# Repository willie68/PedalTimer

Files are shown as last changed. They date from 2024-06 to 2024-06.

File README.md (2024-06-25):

# PedalTimer

A small clock for your guitar pedal board, that counts up or down to measure the duration of songs or to time your performance when you are limited on time.

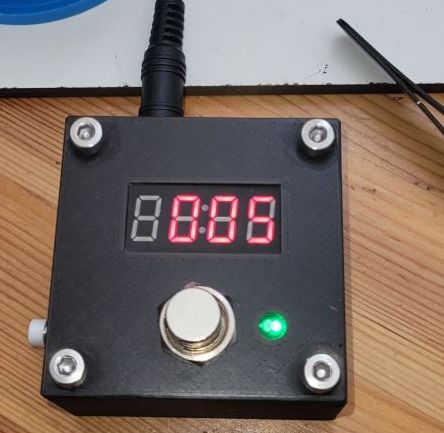
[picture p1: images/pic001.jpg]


The github project site: https://github.com/willie68/PedalTimer

For schematic see wokwi project: https://wokwi.com/projects/400030668740998145

For the case see https://www.tinkercad.com/things/1SspvxZFjsm-pedal-timer

# Description

## Introduction 

Pedal Timer is a small clock for your guitar pedal board. It can count up to measure the duration of songs or down to time your performance when you are limited on time. It can be easily configured even with your foot. 

It has a nice Display, showing time and a small multi color LED for showing the state of the Timer.

## Startup

First the unit show up the firmware of your device. (here it's the 0.06 Version)



After 2 Seconds the unit shows the actual mode



t: St means Stopwatch mode, which is the mode for measure times.

If configured in Count down mode, this will show up:



After another 2 seconds, the unit will switch to operating mode.



## Stopwatch mode

Now you are ready to measure times. A short press on the foot switch will start and stop the timer. You can start and stop as often as you like, the unit will always start from the former time. A long press will reset the timer. The time shown in `minutes:seconds`. This will work 'til 99:59, than an overun will happen (timer start again with 00:00) When running the LED will lit up green and the colon in the middle are blinking.

## Countdown Mode

The display always shows the remaining time in countdown mode.



Start/Stop/Reset works the same as in ST mode. When running the LED will lit up green and the colon in the middle are blinking. If the remaining time > 90 min, the display is showing the `hours:minutes`. If you under run the time, this is indicated by an minus in front of the time. 



## Configuration Mode

To start the configuration mode simply press and hold the button on start until you see the menu entry (after showing firmware and mode) , or do a double click, if St or cd is stopped:



for all steps in the configuration: single click means: next value, long press means: next Entry. The unit will always show the last configured value. if you can configure the value the LED will lit up blue. After the long press, the LED will be off and the configured value will be shown for 1 second. Than the display will show the next configuration value. On double click in every configuration you will exit the configuration without saving the actual config value.

### Brightness



First configuration is the display brightness. The value can range from 1..7. You will see the result only in normal operation modes. In configuration the brightness is always set to max. (So you can always see the display for configuration) 

### Operation Mode

  

There are 2 modes of operation: Stopwatch, shown by St and Count down shown by cd.

### Countdown time



Next you can configure the Countdown time in minutes. It ranges from 5 to 240 minutes  in 5 minutes steps. And it rolls over, so after 240 min -> 5 min. Long press stores the value.

### Warning time (Alarm)



You can setup a warning time from 0..15 min. 0 disables the warning. 

- **St mode**: the LED will lit up in RED (instead of green) if the elapsed time is longer than the warning time.

- **cd mode**: the LED will lit up in RED (instead of green) if the remaining time is shorter than the warning time.

# Building our own version

## BOM

What you need:

- arduino nano or compatible
- footswitch spst (single pole single throw) german: einen Fußtaster.
- 4x Digit TM1637 Display with  double point
- a 5mm RGB WS2812b short head LED
- a small SPST switch for manual input by hand
- 3d printed case
- 4 melting nuts M4 and 4 M4x9mm screws
- chicken feed (which means: cables, solder and stuff like that)

for 9V power

- lumberg DC socket
- 9V/5V converter

## Building up

Before you can start, if you have a nano, the display or any other component with pin heads, remove (desolder) them. In the case there is not enough room for that. Than build all up with short cables. Beware of the DC Socket. You have to solder it, after installing the socket. Because this is the only hardware part going from outside to inside. All others can be soldered before. Glue all the other parts into the case with  hot glue. For the RGB LED you can use super glue.  

Than you are ready to program the nano. The project is build with VS Code and Platform.IO. Simply load the project into VS Code and than you can program the nano. Maybe you have to switch the version for your nano. I have build this up with `nanoatmega328new`  but some other nanos where sold with an older boot loader so you have to use `nanoatmega328`. You can switch this in the platformio.ini file.

### building images

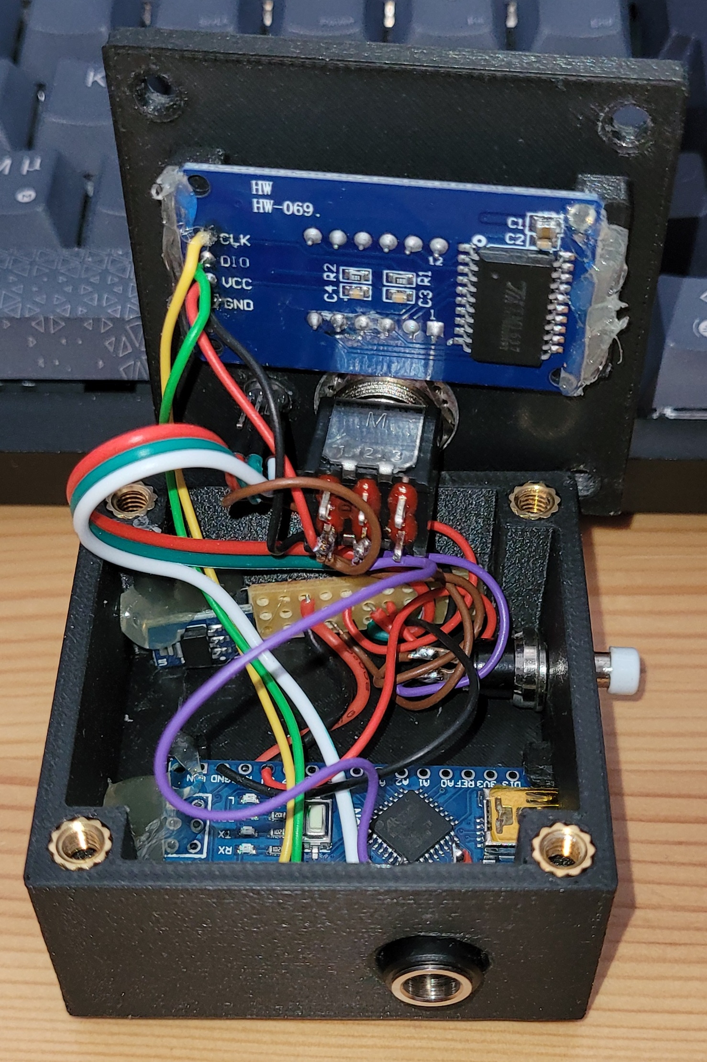
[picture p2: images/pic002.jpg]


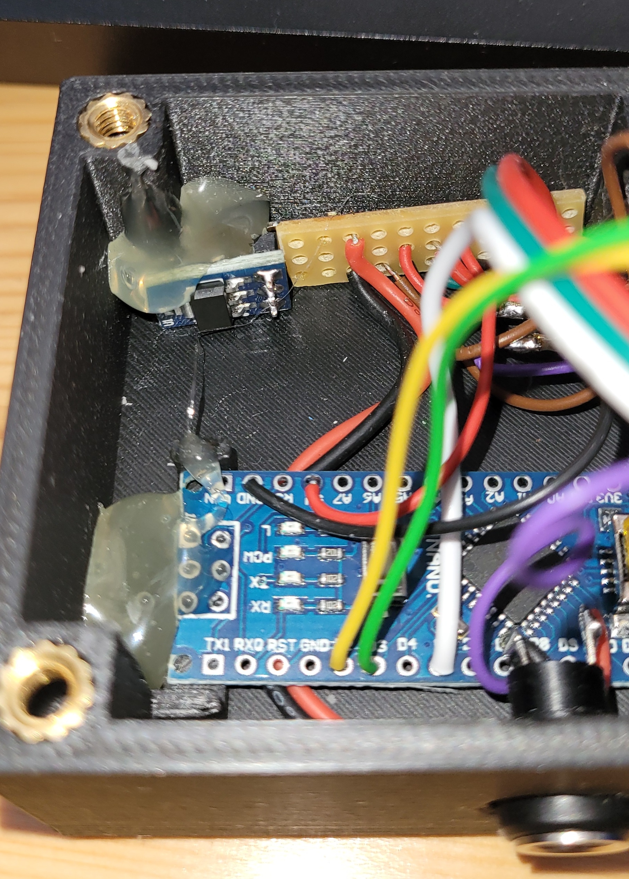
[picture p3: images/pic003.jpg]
Detail view of the power supply

## Schematics

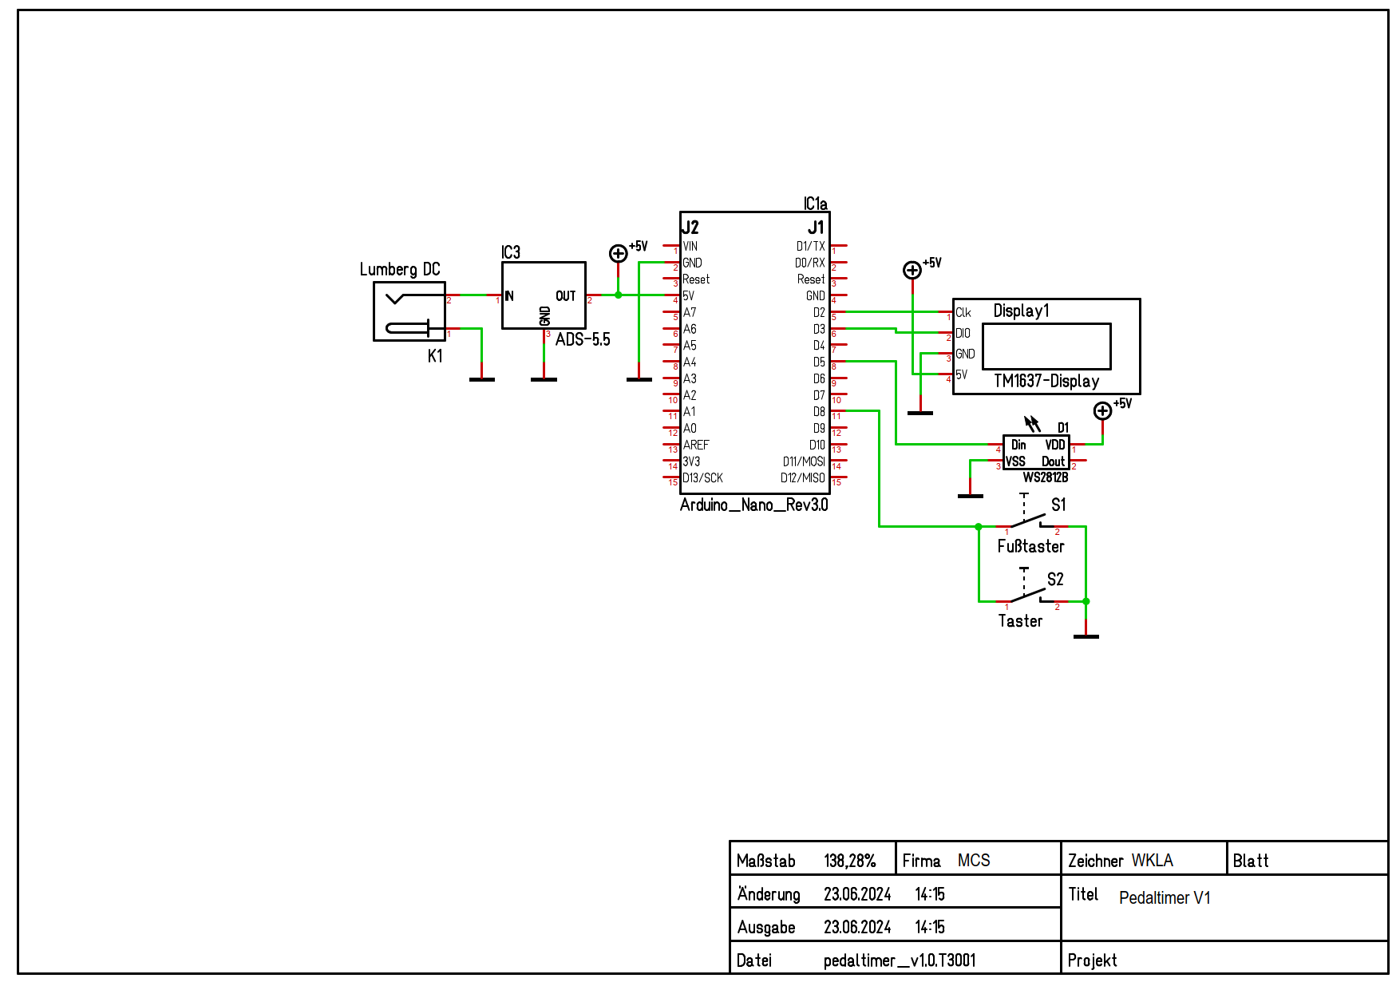
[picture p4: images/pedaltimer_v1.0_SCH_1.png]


<u>2024 WK-Music</u>

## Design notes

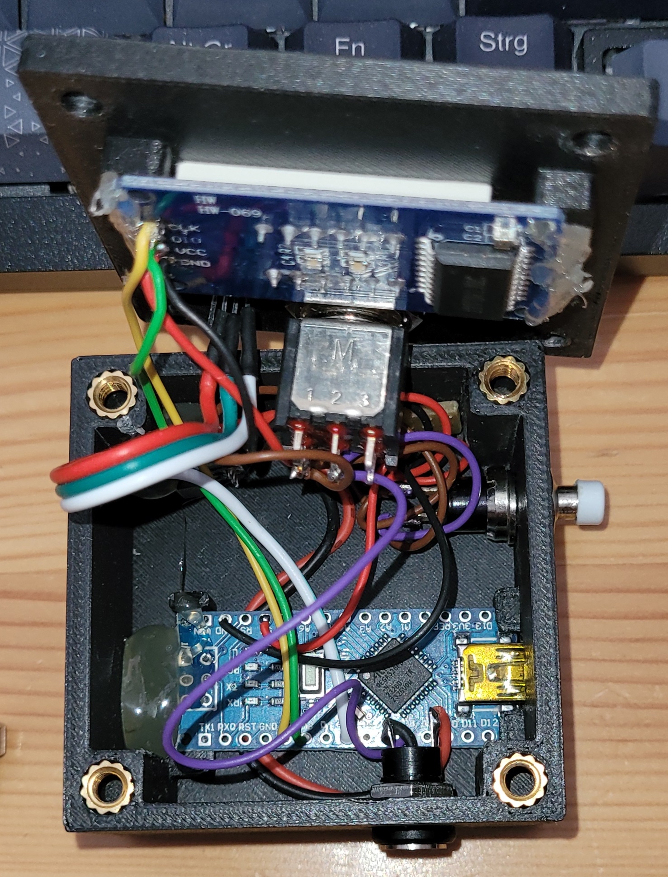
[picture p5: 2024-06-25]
images/pic004.jpg

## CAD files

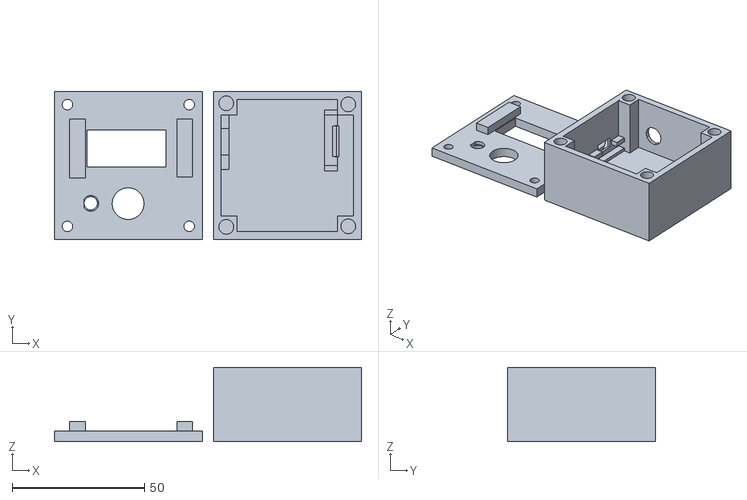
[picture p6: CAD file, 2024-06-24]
hardware/Pedal timer.stl
116.0 x 56.0 x 28.0

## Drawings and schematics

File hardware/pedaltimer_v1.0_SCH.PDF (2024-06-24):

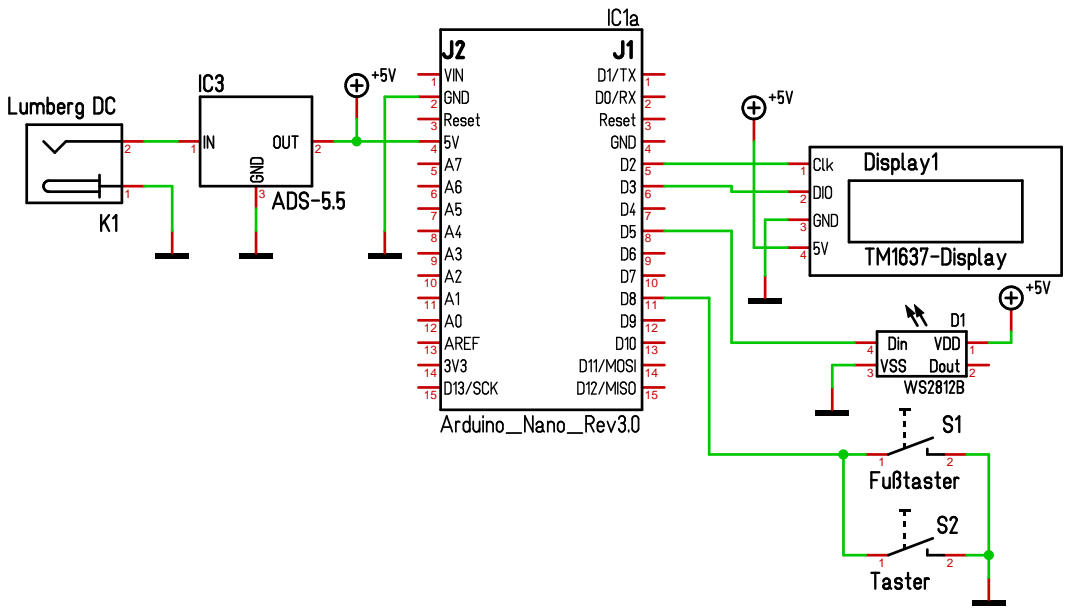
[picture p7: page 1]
Pedaltimer V1; MCS; WKLA ⁴³

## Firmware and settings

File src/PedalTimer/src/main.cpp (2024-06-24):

// this little Project is for my bandmates
// i have to measure the length of our songs,
// so i simply design this. A nano, a footbutton and a TM1637 display is all i need.
// short tap starts/stop/restart the timer
// long tap reset the timer, northing more
#include <arduino.h>
#include <TM1637Display.h>
#include "avdweb_Switch.h"
#include <eeprom.h>
#include <Adafruit_NeoPixel.h>

// #define debug
// #define serial

// Version
#define VS_MAJ 0
#define VS_MIN 8
// constants
#define ON 1
#define OFF 0
// Display
#define CLK 2
#define DIO 3
// Footswitch
#define FS 8
// RGB LED
#define LED_PIN 5

const uint8_t TTD[] = {SEG_F | SEG_G | SEG_E | SEG_D};
const uint8_t STD[] = {SEG_A | SEG_F | SEG_G | SEG_C | SEG_D, SEG_F | SEG_G | SEG_E | SEG_D};
const uint8_t CDD[] = {SEG_G | SEG_E | SEG_D, SEG_B | SEG_G | SEG_E | SEG_D | SEG_C};
const uint8_t CPD[] = {SEG_G | SEG_E | SEG_D};
const uint8_t MND[] = {SEG_G};
const uint8_t MED[] = {
    SEG_A | SEG_F | SEG_E | SEG_B | SEG_C,
    SEG_A | SEG_F | SEG_G | SEG_E | SEG_D,
    SEG_G | SEG_E | SEG_C,
    SEG_C | SEG_E | SEG_D,
};

// show the given time
void showTime(int act);
// lit the LED
void led(bool on);
// toggle the LED output
void toggled();
// checking if the LED is on
bool isLED();
// read the timer mode
void readCdm();
// do the timer setup
void doSetup();
// showing the given count down mode
void showCdm(bool mode);
// showing the count down time for setup
void setupCdmTimeShow(int time);
// showing the count down time
void showCdmTime(int time);
// write out the config via serial
void outputConfig();

Adafruit_NeoPixel pixel(1, LED_PIN, NEO_RGB + NEO_KHZ800);
TM1637Display display = TM1637Display(CLK, DIO);
Switch fs = Switch(FS);

const uint32_t RED = pixel.Color(0xff, 0, 0);
const uint32_t BLUE = pixel.Color(0, 0, 0xff);
const uint32_t GREEN = pixel.Color(0, 0xff, 0);

long start = 0L;
bool started = false;
bool ledOn = false;
// count down mode, if true the timer operate in count down mode.
// Taking the actual time from the eeprom and on first click starts the count down.
// Default mode is taken from the eeprom, too
bool cdm = true;
byte cdmtime = 45;
byte bright = 4;
// time to start the warning, blinking LED,
// in CD mode: time in minutes, when cd time is lower than this, the alarm starts
// in ST mode: time in minutes, when time is greater than this, the alarm starts
byte warningtime = 4;
bool alarm = false;
unsigned long alarmblk = 0;

// actual color of led
uint32_t color = GREEN;
bool endsetup = false;

void setupPixel()
{
  pixel.begin(); // INITIALIZE NeoPixel strip object (REQUIRED)
  pixel.setBrightness(7 * 8);
  pixel.show();

  color = BLUE;
}

void showVersion()
{
  display.clear();
  display.setBrightness(7);
  display.showNumberDec(VS_MAJ, false, 1, 1);
  display.showNumberDec(VS_MIN, true, 2, 2);
  display.showNumberHexEx(0xF, 0xF, false, 1, 0);

  led(ON);
  for (byte i = 0; i < 200; i++)
  {
    fs.poll();
    delay(10);
  }
}

void afterSetup()
{
#ifdef serial
  color = GREEN;
#endif

  outputConfig();
  display.clear();
  display.setBrightness(bright);
  pixel.setBrightness(bright * 8);
  cdm ? showCdmTime(0) : showTime(0);
  led(OFF);
}

void setup()
{
#ifdef serial
  Serial.begin(115200);
#endif

  setupPixel();

  showVersion();

  readCdm();
  display.clear();
  display.setSegments(TTD, 1, 0);
  showCdm(cdm);
  for (byte i = 0; i < 200; i++)
  {
    fs.poll();
    delay(10);
  }
  if (fs.on())
  {
    doSetup();
  }

  afterSetup();
}

long actualSec, oldSec = 0;
bool colon = false;

void loop()
{
  fs.poll();
  if (fs.doubleClick())
  {
    if (!started)
    {
      doSetup();
      afterSetup();
      actualSec = 0;
      start = 0L;
    }
  }
  if (fs.longPress())
  {
    started = false;
    actualSec = 0;
    colon = false;
    display.setColon(colon);
    led(OFF);
  }
  if (fs.singleClick())
  {
    if (!started)
    {
      started = true;
      start = millis() - (actualSec * 1000L);
      oldSec = -1;
    }
    else
    {
      started = false;
    }
    led(started);
    colon = started;
    display.setColon(colon);
  }
  if (started)
  {
    actualSec = (millis() - start) / 1000L;
    if (warningtime > 0)
    {
      if (cdm)
      {
        alarm = (int(cdmtime) * 60) - int(actualSec) < (int(warningtime) * 60);
      }
      else
      {
        alarm = actualSec > (warningtime * 60L);
      }
    }
    if (alarm)
    {
      color = RED;
      if (alarmblk < millis())
      {
        alarmblk = millis() + 500;
        toggled();
        display.setBrightness(7);
      }
    }
    else
    {
      color = GREEN;
    }
    led(started);
  }
  if (actualSec != oldSec)
  {
    display.setColon(colon);
    if (cdm)
    {
      showCdmTime(actualSec);
    }
    else
    {
      showTime(actualSec);
    }
    colon = !colon;
    oldSec = actualSec;
  }
}

void showTime(int act)
{
  bool neg = act < 0;
  int t = abs(act);
  byte sec = t % 60;
  byte min = (t - sec) / 60;
  if (neg)
  {
    display.setSegments(MND, 1, 0);
    display.showNumberDec(min, false, 1, 1);
  }
  else
  {
    display.showNumberDec(min, false, 2, 0);
  }
  display.showNumberDec(sec, true, 2, 2);
}

void showCdmTime(int ct)
{
  int time = (cdmtime * 60) - int(ct);
#ifdef serial
  Serial.println(time);
#endif
  if ((time <= 90 * 60) && (time > -9 * 60))
  {
    showTime(long(time));
  }
  else
  {
    int value = time / 60;
    // display.clear();
    display.showNumberDec(value, false, 4, 0);
  }
}

void led(bool on)
{
  if (!on)
  {
    pixel.clear();
    pixel.show();
  }
  else
  {
    pixel.setPixelColor(0, color);
    pixel.show();
  }
  ledOn = on;
}

void toggled()
{
  led(!isLED());
}

bool isLED()
{
  return ledOn;
}

void readCdm()
{
#ifdef debug
  cdm = true;
#else
  byte value = EEPROM.read(0x00);
  cdm = (value > 0) && (value < 0xFF);
  value = EEPROM.read(0x01);
  if (value <= 240)
  {
    cdmtime = value;
  }
  bright = EEPROM.read(0x02);
  if (bright == 0xff)
  {
    bright = 4;
  }
  bright = bright % 7;
  warningtime = EEPROM.read(0x03);
  if (warningtime == 0xff)
  {
    warningtime = 9;
  }
  warningtime = warningtime % 16;
#endif
}

void setupMode()
{
  led(ON);
  display.clear();
  display.setColon(ON);
  display.setSegments(TTD, 1, 0);
  showCdm(cdm);
  bool end = false;
  bool value = cdm;
  do
  {
    fs.poll();
    if (fs.doubleClick())
    {
      endsetup = true;
      return;
    }
    if (fs.longPress())
    {
      cdm = value;
      EEPROM.write(0x00, cdm ? 1 : 0);
      end = true;
    }
    else if (fs.singleClick())
    {
      value = !value;
      showCdm(value);
    }
  } while (!end);
  led(OFF);
  display.setColon(OFF);
  display.clear();
  display.setSegments(TTD, 1, 0);
  showCdm(cdm);
  delay(1000);
}

void setupCdmTimeShow(int time)
{
  display.setSegments(CPD, 1, 0);
  display.showNumberDec(time, true, 3, 1);
}

void setupCDTime()
{
  led(ON);
  display.setColon(OFF);
  display.clear();
  setupCdmTimeShow(cdmtime);
  bool end = false;
  byte value = cdmtime;
  do
  {
    if ((value > 240) || (value < 5))
    {
      value = 5;
      setupCdmTimeShow(value);
    }
    fs.poll();
    if (fs.doubleClick())
    {
      endsetup = true;
      return;
    }
    if (fs.longPress())
    {
      EEPROM.write(0x01, value);
      cdmtime = value;
      end = true;
    }
    else if (fs.singleClick())
    {
      value += 5;
      setupCdmTimeShow(value);
    }
  } while (!end);
  led(OFF);
  display.clear();
  setupCdmTimeShow(cdmtime);
  delay(1000);
}

void setupBrigthnessShow(byte value)
{
  display.showNumberHexEx(0xb, 0, false, 1, 0);
  display.showNumberDec(value, false, 1, 3);
}

void setupBrightness()
{
  led(ON);
  display.setColon(ON);
  display.clear();
  setupBrigthnessShow(bright);
  bool end = false;
  byte value = bright;
  do
  {
    if (value > 7)
    {
      value = 0;
      setupBrigthnessShow(value);
    }
    fs.poll();
    if (fs.doubleClick())
    {
      endsetup = true;
      return;
    }
    if (fs.longPress())
    {
      bright = value;
      EEPROM.write(0x02, value);
      end = true;
    }
    else if (fs.singleClick())
    {
      value++;
      setupBrigthnessShow(value);
    }
  } while (!end);
  led(OFF);
  display.setColon(OFF);
  display.clear();
  setupBrigthnessShow(bright);
  delay(1000);
}

void setupWarningTimeShow(byte value)
{
  display.showNumberHexEx(0xa, 0, false, 1, 0);
  display.showNumberDec(value, true, 2, 2);
}

void setupWarningTime()
{
  led(ON);
  display.setColon(ON);
  display.clear();
  setupWarningTimeShow(warningtime);
  bool end = false;
  byte value = warningtime;
  do
  {
    if (value > 15)
    {
      value = 0;
      setupWarningTimeShow(value);
    }
    fs.poll();
    if (fs.doubleClick())
    {
      endsetup = true;
      return;
    }
    if (fs.longPress())
    {
      warningtime = value;
      EEPROM.write(0x03, value);
      end = true;
    }
    else if (fs.singleClick())
    {
      value++;
      setupWarningTimeShow(value);
    }
  } while (!end);
  led(OFF);
  display.setColon(OFF);
  display.clear();
  setupWarningTimeShow(warningtime);
  delay(1000);
}

void doSetup()
{
  color = BLUE;
  endsetup = false;

  // show menu text
  display.clear();
  display.setColon(false);
  display.setSegments(MED, 4, 0);
  delay(2000);
  fs.poll();
  // setup display brightness
  setupBrightness();
  if (endsetup)
    return;
  // Set counter mode
  setupMode();
  if (endsetup)
    return;
  // now if cdm is selected, let's adjust the count down time
  setupCDTime();
  if (endsetup)
    return;
  // setup the warning time
  setupWarningTime();
  if (endsetup)
    return;
}

void showCdm(bool mode)
{
  if (mode)
  {
    display.setSegments(CDD, 2, 2);
  }
  else
  {
    display.setSegments(STD, 2, 2);
  }
}

void outputConfig()
{
  Serial.print("Bright: ");
  Serial.println(bright);
  Serial.print("Mode: ");
  Serial.println(cdm ? "countdown" : "stoptime");
  Serial.print("Warning time: ");
  Serial.println(warningtime);
  Serial.print("Countdown time: ");
  Serial.println(cdmtime);
}

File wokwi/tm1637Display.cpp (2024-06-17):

//  Author: avishorp@gmail.com
//
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
extern "C" {
  #include <stdlib.h>
  #include <string.h>
  #include <inttypes.h>
}

#include "tm1637Display.h"
#include <Arduino.h>

#define TM1637_I2C_COMM1    0x40
#define TM1637_I2C_COMM2    0xC0
#define TM1637_I2C_COMM3    0x80

//
//      A
//     ---
//  F |   | B
//     -G-
//  E |   | C
//     ---
//      D
const uint8_t digitToSegment[] = {
 // XGFEDCBA
  0b00111111,    // 0
  0b00000110,    // 1
  0b01011011,    // 2
  0b01001111,    // 3
  0b01100110,    // 4
  0b01101101,    // 5
  0b01111101,    // 6
  0b00000111,    // 7
  0b01111111,    // 8
  0b01101111,    // 9
  0b01110111,    // A
  0b01111100,    // b
  0b00111001,    // C
  0b01011110,    // d
  0b01111001,    // E
  0b01110001     // F
  };

static const uint8_t minusSegments = 0b01000000;

TM1637Display::TM1637Display(uint8_t pinClk, uint8_t pinDIO, unsigned int bitDelay)
{
	// Copy the pin numbers
	m_pinClk = pinClk;
	m_pinDIO = pinDIO;
	m_bitDelay = bitDelay;

	// Set the pin direction and default value.
	// Both pins are set as inputs, allowing the pull-up resistors to pull them up
    pinMode(m_pinClk, INPUT);
    pinMode(m_pinDIO,INPUT);
	digitalWrite(m_pinClk, LOW);
	digitalWrite(m_pinDIO, LOW);
}

void TM1637Display::setBrightness(uint8_t brightness, bool on)
{
	m_brightness = (brightness & 0x7) | (on? 0x08 : 0x00);
}

void TM1637Display::setColon(bool colon)
{
  m_colon = colon;
}

void TM1637Display::setSegments(const uint8_t segments[], uint8_t length, uint8_t pos)
{
    // Write COMM1
	start();
	writeByte(TM1637_I2C_COMM1);
	stop();

	// Write COMM2 + first digit address
	start();
	writeByte(TM1637_I2C_COMM2 + (pos & 0x03));

	// Write the data bytes
    uint8_t currentByte = 0x00;
	for (uint8_t k=0; k < length; k++) {
      currentByte = segments[k] & 0x7f;
      if(k == COLON_POSITION){
        if(m_colon){
          currentByte |= 0x80;
        }
      }
      writeByte(currentByte);
	}
	stop();

	// Write COMM3 + brightness
	start();
	writeByte(TM1637_I2C_COMM3 + (m_brightness & 0x0f));
	stop();
}

void TM1637Display::clear()
{
    uint8_t data[] = { 0, 0, 0, 0 };
	setSegments(data);
}

void TM1637Display::showNumberDec(int num, bool leading_zero, uint8_t length, uint8_t pos)
{
  showNumberDecEx(num, 0, leading_zero, length, pos);
}

void TM1637Display::showNumberDecEx(int num, uint8_t dots, bool leading_zero,
                                    uint8_t length, uint8_t pos)
{
  showNumberBaseEx(num < 0? -10 : 10, num < 0? -num : num, dots, leading_zero, length, pos);
}

void TM1637Display::showNumberHexEx(uint16_t num, uint8_t dots, bool leading_zero,
                                    uint8_t length, uint8_t pos)
{
  showNumberBaseEx(16, num, dots, leading_zero, length, pos);
}

void TM1637Display::showNumberBaseEx(int8_t base, uint16_t num, uint8_t dots, bool leading_zero,
                                    uint8_t length, uint8_t pos)
{
    bool negative = false;
	if (base < 0) {
	    base = -base;
		negative = true;
	}


    uint8_t digits[4];

	if (num == 0 && !leading_zero) {
		// Singular case - take care separately
		for(uint8_t i = 0; i < (length-1); i++)
			digits[i] = 0;
		digits[length-1] = encodeDigit(0);
	}
	else {
		//uint8_t i = length-1;
		//if (negative) {
		//	// Negative number, show the minus sign
		//    digits[i] = minusSegments;
		//	i--;
		//}
		
		for(int i = length-1; i >= 0; --i)
		{
		    uint8_t digit = num % base;
			
			if (digit == 0 && num == 0 && leading_zero == false)
			    // Leading zero is blank
				digits[i] = 0;
			else
			    digits[i] = encodeDigit(digit);
				
			if (digit == 0 && num == 0 && negative) {
			    digits[i] = minusSegments;
				negative = false;
			}

			num /= base;
		}
    }
	
	if(dots != 0)
	{
		showDots(dots, digits);
	}
    
    setSegments(digits, length, pos);
}

void TM1637Display::bitDelay()
{
	delayMicroseconds(m_bitDelay);
}

void TM1637Display::start()
{
  pinMode(m_pinDIO, OUTPUT);
  bitDelay();
}

void TM1637Display::stop()
{
	pinMode(m_pinDIO, OUTPUT);
	bitDelay();
	pinMode(m_pinClk, INPUT);
	bitDelay();
	pinMode(m_pinDIO, INPUT);
	bitDelay();
}

bool TM1637Display::writeByte(uint8_t b)
{
  uint8_t data = b;

  // 8 Data Bits
  for(uint8_t i = 0; i < 8; i++) {
    // CLK low
    pinMode(m_pinClk, OUTPUT);
    bitDelay();

	// Set data bit
    if (data & 0x01)
      pinMode(m_pinDIO, INPUT);
    else
      pinMode(m_pinDIO, OUTPUT);

    bitDelay();

	// CLK high
    pinMode(m_pinClk, INPUT);
    bitDelay();
    data = data >> 1;
  }

  // Wait for acknowledge
  // CLK to zero
  pinMode(m_pinClk, OUTPUT);
  pinMode(m_pinDIO, INPUT);
  bitDelay();

  // CLK to high
  pinMode(m_pinClk, INPUT);
  bitDelay();
  uint8_t ack = digitalRead(m_pinDIO);
  if (ack == 0)
    pinMode(m_pinDIO, OUTPUT);


  bitDelay();
  pinMode(m_pinClk, OUTPUT);
  bitDelay();

  return ack;
}

void TM1637Display::showDots(uint8_t dots, uint8_t* digits)
{
    for(int i = 0; i < 4; ++i)
    {
        digits[i] |= (dots & 0x80);
        dots <<= 1;
    }
}

uint8_t TM1637Display::encodeDigit(uint8_t digit)
{
	return digitToSegment[digit & 0x0f];
}

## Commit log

2024-06-12 WIP: adding count down timer
2024-06-12 WIP: make the count down timer nice
2024-06-14 WIP: more feature, warning time, alarm
    - adding possibility to useserial monitor on wokwi simulator, baudrate 115200
    - adding alarm LED in wokwi schematic
    - adding debug compiler flag, for predefining EEPROM config on startup (Mostly needed for wokwi simulator)
    - adding serial output for debugging purpose
    - adding alarm LED
    - adding warning time, where the AlarmLED is lit up, display brigthness set to 7
    - removing some bugs on timer overflow
    [main.cpp]
2024-06-15 some changes in Project
    - adding readme with references to case and schematic
    - adding RGB LED as LED, remove alarm and onboard LED
    -
2024-06-15 some changes in Project
    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
2024-06-17 new hardware folder
    [Pedal_timer.stl]
2024-06-19 case: countersink the dc socket
    Fw: - some initialisation after leaving the config mode
    [Pedal timer.stl, Pedal_timer.stl]
2024-06-24 adding little pcb holder to case
    [Pedal timer.stl, Pedal_timer.stl]
